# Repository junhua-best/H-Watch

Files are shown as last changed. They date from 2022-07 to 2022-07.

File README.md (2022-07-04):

# H-Watch
基于stm32L4系列的的低功耗智能手表
   智能手表是当前智能穿戴设备的主流产品之一。将手表内置智能化系统，连接于网络而实现多功能，可同步手机中的电话、短信、邮件、照片、音乐等。同时，智能手表还成为了运动的助手，可准确追踪走路的步数和消耗的能量；还可以通过内嵌的传感器，监测穿戴者的脉搏、心跳等身体状况的变化。近年来，智能手表热潮的掀起使得这一市场不断壮大，也有越来越多科技厂商投身其中。
	针对市面上的智能手表价格偏高，且普遍功耗表现差等特点，本文介绍了一种基于STM32l431系列的超低功耗微控制器的低成本智能手表“H-Watch”，从硬件到软件上的开发全过程。
	本文首先介绍了H-Watch的硬件相关的设置，搭载STM32L431CCU6的低功耗微控制器、低功耗蓝牙芯片、陀螺仪、温湿度传感器、磁力计、触摸按钮、振动马达、LCD屏幕等硬件外设，本文前期阐述了这些硬件在H-Watch中起到的作用。而在显示方面，H-Watch移植了业界常用的LVGL图形库，H-Watch拥有多个精美的界面，并具有流畅的动画效果，本文将在软件上仿真的效果以及实际手表的显示效果以图片的形式呈现。在操作系统方面，为了系统性能最大化、多个模块互相不耦合等特点，H-Watch使用FREERTOS实时操作系统，在H-Watch的研发过程中，软件系统设计被视作最为重要的一部分，本文着重阐述了各个功能模块的软件设计。
  本文将H-Watch的显示根据功能拆分设计为七个页面：主界面、关于、设置、备忘录、秒表、亮度设置、菜单。在软件系统层面拆分成六个主任务：蓝牙通信、时间更新、传感器数据更新、睡眠检测、按键更新、LVGL更新。H-Watch最终具有的功能包括：秒表、时间设置、亮度控制、时间日期显示、天气显示、温湿度值显示、电量值显示、步数记录、备忘录等。在续航方面，能够做到一次充电后，可以正常使用两个月的时间。

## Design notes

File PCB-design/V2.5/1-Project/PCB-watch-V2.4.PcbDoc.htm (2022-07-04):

Reporting Options

# File in Newer Format

Date | : | 2022/4/30
Time | : | 0:15:09
Filename | : | D:\作业文档\毕业设计_智能手表\裸跑版参考\原版资源图片\Hwatch-master\2-PCB-design\V2.5\1-Project\PCB-watch-V2.4.PcbDoc

Version | Warning
Release 15.1 | CAUTION - Support Multi-line PCB Text added.
Release 16.0 | CAUTION - Pad/Via hole size tolerance value added.
Release 17.0 | CAUTION - Component parameters added.
Release 17.0 | CAUTION - Support of backdrilling
Release 17.1 | CAUTION - Support of waived violations
Release 17.1 | CAUTION - Support of object specific keepouts
Release 20.0 | CAUTION - Support of propagation delay for primitives

This file was generated by a later version of the software

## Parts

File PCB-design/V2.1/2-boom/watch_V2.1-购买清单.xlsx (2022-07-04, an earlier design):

Comment | Description | Designator | Footprint | LibRef | Quantity
AN9520-245 | 2.4G全向天线 蓝牙天线 陶瓷贴片 WIFI内置 | AN1 | AN-5120 | AN9520-245 | 1
CC2541 | 低功耗蓝牙芯片 | B1 | QFN40-CC254X | CC2541 | 1
100nF | 0402封装电容, 贴片电容 | BC1, BC2, BC4, BC5, BC15, C5, C6, C9, C10, C11, C15, C16, C18, C19 | CC1005-0402 | Cap Chip 0402, Chip capacitor | 14
220PF | 0402封装电容 | BC3 | CC1005-0402 | Cap Chip 0402 | 1
18PF | 0402封装电容 | BC6, BC10 | CC1005-0402 | Cap Chip 0402 | 2
1PF | 0402封装电容, 贴片电容 | BC7, BC8, BC9, C7, C8 | CC1005-0402 | Cap Chip 0402, Chip capacitor | 5
15PF | 0402封装电容, 贴片电容 | BC11, BC14, C1, C2 | CC1005-0402 | Cap Chip 0402, Chip capacitor | 4
27PF | 0402封装电容 | BC12, BC13 | CC1005-0402 | Cap Chip 0402 | 2
1nH | 0402封装的电感 | BL1, BL2 | Inductor-0402 | Inductor-0402 | 2
2nH | 0402封装的电感 | BL3, BL4, BL5 | Inductor-0402 | Inductor-0402 | 3
56KR | 贴片电阻 | BR1 | CR1005-0402 | Chip resistor | 1
22pF | 贴片电容 | C3, C4 | CC1005-0402 | Chip capacitor | 2
4.7uF | 贴片电容 | C12 | CC1005-0402 | Chip capacitor | 1
2.2uF | 贴片电容 | C13 | CC1005-0402 | Chip capacitor | 1
0.22uF | 贴片电容 | C14 | CC1005-0402 | Chip capacitor | 1
10uF | 贴片电容 | C17, C20, C21 | CC1005-0402 | Chip capacitor | 3
1uF | 贴片电容 | C22, C24 | CC1005-0402 | Chip capacitor | 2
10nF | 贴片电容 | C23, C25 | CC1005-0402 | Chip capacitor | 2
TFT LED | 1.3寸显示屏幕 | L1 | LCD-1.3-(2) | LCD-IPSscreen-1.3 | 1
3.3uH | 贴片电感 | L2 | Inductor-0805 | Chip inductor | 1
power |  | P2, P3 | POWER-3.7V | power | 2
10KR | 贴片电阻 | R1, R2 | CR1005-0402 | Chip resistor | 2
1K | 贴片电阻 | R3, R21, R22, R24 | CR1005-0402 | Chip resistor | 4
10K | 贴片电阻 | R4, R8, R9, R10, R11, R12, R17, R18, R19, R20, R25, R26, R27 | CR1005-0402 | Chip resistor | 13
47K | 贴片电阻 | R5, R6, R7 | CR1005-0402 | Chip resistor | 3
1M | 贴片电阻 | R13 | CR1005-0402 | Chip resistor | 1
178K | 贴片电阻 | R14 | CR1005-0402 | Chip resistor | 1
1.5K | 贴片电阻 | R15, R16 | CR1005-0402 | Chip resistor | 2
2K | 贴片电阻 | R23 | CR1005-0402 | Chip resistor | 1
SH1.0-7P | 间距为1mm的端子 | SH1 | SH1.0-6P | SH1.0-7P | 1
STM32L431CCU6 | stm32低功耗单片机 主频80MHz | U1 | STM32-UFQFPN48_N | STM32L431CCU6 | 1
BS812A-1 | 触摸按键 两路 SOP23-6封装极简电路 | U2 | SOT23-6 | BS812A-1 | 1
W25Q256JVEIQ | FLASH | U3 | WSON-8_L8.0-W6.10-P1.27-TL-EP | W25Q256JVEIQ | 1
MMBT3904TT1G | NPN 电流 - 集电极（Ic）（最大值）：200mA 电压 - 集射极击穿（最大值）：40V SOT-23-3 | U4, U12 | SOT-416 | MMBT3904TT1G | 2
HMC5883L | 三轴罗盘 | U5 | LPCC-16_L3.0-W3.0-P0.50-BL | HMC5883L | 1
MPU6050 | 陀螺仪 | U6 | QFN24 - duplicate | MPU6050 | 1
SI7020 | 温湿度传感器芯片 | U7 | DFN-6 | SI7020 | 1
TPS22965 | DFN-8 功率开关芯片 TPS22965DSGR | U8 | UDFN-8 | TPS22965 | 1
TPS63000 | 宽电压电源转换芯片输出3.3V输入1V至6V | U9 | SON10 | TPS63000 | 1
CH340E | usd转串口芯片 MSOP10封装 | U10 | MSOP-10 | CH340E | 1
BQ24040 | 1A 具有自动启动功能的单输入，单节锂离子和锂聚合物电池充电 器 | U11 | WSON-10_L2.0-W2.0-P0.40-BL-EP | BQ24041 | 1
Tpye-c 16P | 16P 封装的TYPE -c接口 4固定插脚 双向 | USB1 | TYPE-C 16P | Tpye-c 16P | 1
32.768Khz | 2012封装的时钟晶振 | X1, X4 | XTAL-2012 | XTAL 2012 | 2
32Mhz | 2016封装的晶振 | X2, X3 | XTAL-2016 | XTAL 2016 | 2

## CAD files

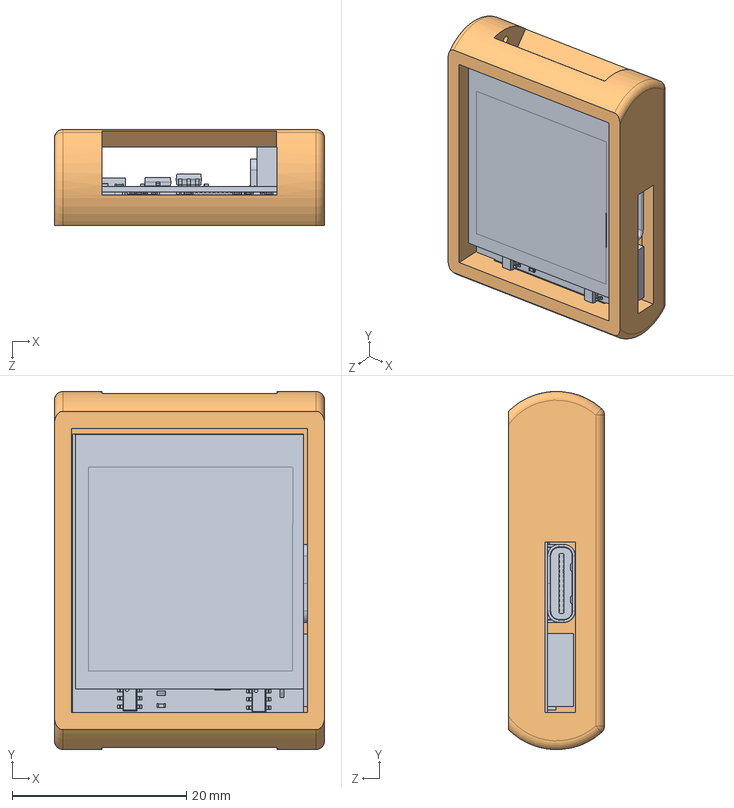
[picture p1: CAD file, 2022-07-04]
3D_design/装配体3.SLDASM
31.0 x 41.0 x 11.0 mm
PCB-watch-V2
外壳

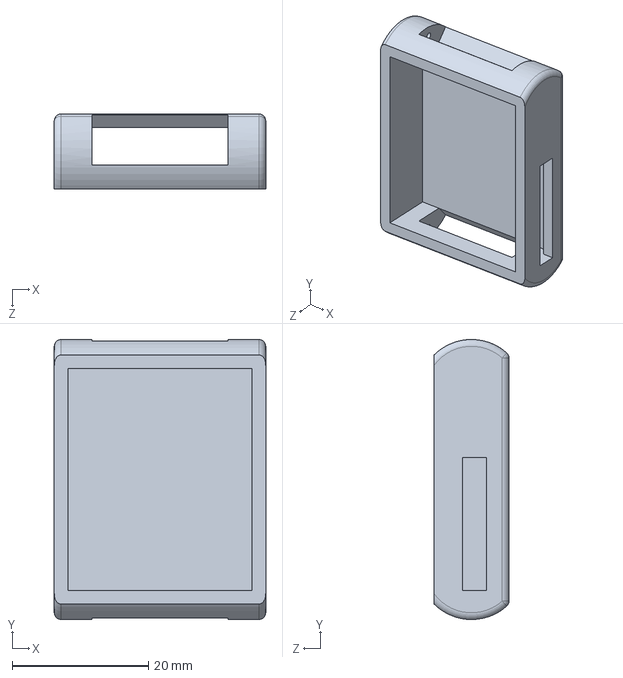
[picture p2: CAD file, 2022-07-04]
3D_design/外壳.SLDPRT
31.0 x 41.0 x 11.0 mm

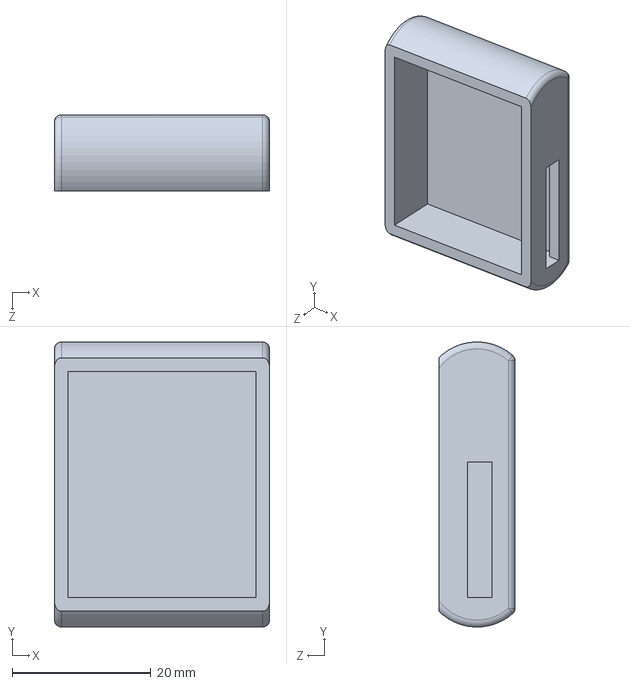
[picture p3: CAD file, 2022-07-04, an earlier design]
3D_design/外壳 - 副本.SLDPRT
31.0 x 41.0 x 11.0 mm

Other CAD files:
3D_design/外壳.STL

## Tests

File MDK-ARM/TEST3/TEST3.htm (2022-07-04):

# Static Call Graph for image TEST3\TEST3.axf

#<CALLGRAPH># ARM Linker, 5060960: Last Updated: Mon Jul 04 18:24:46 2022

### Maximum Stack Usage = 948 bytes + Unknown(Cycles, Untraceable Function Pointers)

### Call chain for Maximum Stack Depth:

lv_img_design ⇒ lv_draw_img ⇒ lv_img_draw_core ⇒ lv_draw_label ⇒ lv_draw_rect ⇒ lv_draw_shadow ⇒ lv_draw_shadow_full ⇒ lv_draw_shadow_full_straight ⇒ lv_draw_fill ⇒ sw_color_fill ⇒ lv_color_mix

### Mutually Recursive functions

- ADC1_IRQHandler ⇒ ADC1_IRQHandler
- lv_obj_get_screen ⇒ lv_obj_get_screen
- refresh_children_position ⇒ refresh_children_position
- BusFault_Handler ⇒ BusFault_Handler
- HardFault_Handler ⇒ HardFault_Handler
- MemManage_Handler ⇒ MemManage_Handler
- UsageFault_Handler ⇒ UsageFault_Handler
- lv_refr_obj ⇒ lv_refr_obj
- lv_refr_get_top_obj ⇒ lv_refr_get_top_obj
- lv_event_send_func ⇒ lv_event_send
- indev_search_obj ⇒ indev_search_obj
- report_style_mod_core ⇒ report_style_mod_core
- refresh_children_style ⇒ refresh_children_style

### Function Pointers

- ADC1_IRQHandler from startup_stm32l431xx.o(.text) referenced from startup_stm32l431xx.o(RESET)
- Ble_task from freertos.o(i.Ble_task) referenced from freertos.o(i.MX_FREERTOS_Init)
- BusFault_Handler from stm32l4xx_it.o(i.BusFault_Handler) referenced from startup_stm32l431xx.o(RESET)
- Button_task from freertos.o(i.Button_task) referenced from freertos.o(i.MX_FREERTOS_Init)
- CAN1_RX0_IRQHandler from startup_stm32l431xx.o(.text) referenced from startup_stm32l431xx.o(RESET)
- CAN1_RX1_IRQHandler from startup_stm32l431xx.o(.text) referenced from startup_stm32l431xx.o(RESET)
- CAN1_SCE_IRQHandler from startup_stm32l431xx.o(.text) referenced from startup_stm32l431xx.o(RESET)
- CAN1_TX_IRQHandler from startup_stm32l431xx.o(.text) referenced from startup_stm32l431xx.o(RESET)
- COMP_IRQHandler from startup_stm32l431xx.o(.text) referenced from startup_stm32l431xx.o(RESET)
- CRS_IRQHandler from startup_stm32l431xx.o(.text) referenced from startup_stm32l431xx.o(RESET)
- DMA1_Channel1_IRQHandler from startup_stm32l431xx.o(.text) referenced from startup_stm32l431xx.o(RESET)
- DMA1_Channel2_IRQHandler from startup_stm32l431xx.o(.text) referenced from startup_stm32l431xx.o(RESET)
- DMA1_Channel3_IRQHandler from stm32l4xx_it.o(i.DMA1_Channel3_IRQHandler) referenced from startup_stm32l431xx.o(RESET)
- DMA1_Channel4_IRQHandler from stm32l4xx_it.o(i.DMA1_Channel4_IRQHandler) referenced from startup_stm32l431xx.o(RESET)
- DMA1_Channel5_IRQHandler from stm32l4xx_it.o(i.DMA1_Channel5_IRQHandler) referenced from startup_stm32l431xx.o(RESET)
- DMA1_Channel6_IRQHandler from stm32l4xx_it.o(i.DMA1_Channel6_IRQHandler) referenced from startup_stm32l431xx.o(RESET)
- DMA1_Channel7_IRQHandler from stm32l4xx_it.o(i.DMA1_Channel7_IRQHandler) referenced from startup_stm32l431xx.o(RESET)
- DMA2_Channel1_IRQHandler from startup_stm32l431xx.o(.text) referenced from startup_stm32l431xx.o(RESET)
- DMA2_Channel2_IRQHandler from startup_stm32l431xx.o(.text) referenced from startup_stm32l431xx.o(RESET)
- DMA2_Channel3_IRQHandler from startup_stm32l431xx.o(.text) referenced from startup_stm32l431xx.o(RESET)
- DMA2_Channel4_IRQHandler from startup_stm32l431xx.o(.text) referenced from startup_stm32l431xx.o(RESET)
- DMA2_Channel5_IRQHandler from startup_stm32l431xx.o(.text) referenced from startup_stm32l431xx.o(RESET)
- DMA2_Channel6_IRQHandler from startup_stm32l431xx.o(.text) referenced from startup_stm32l431xx.o(RESET)
- DMA2_Channel7_IRQHandler from startup_stm32l431xx.o(.text) referenced from startup_stm32l431xx.o(RESET)
- Data_task from freertos.o(i.Data_task) referenced from freertos.o(i.MX_FREERTOS_Init)
- DebugMon_Handler from stm32l4xx_it.o(i.DebugMon_Handler) referenced from startup_stm32l431xx.o(RESET)
- EXTI0_IRQHandler from stm32l4xx_it.o(i.EXTI0_IRQHandler) referenced from startup_stm32l431xx.o(RESET)
- EXTI15_10_IRQHandler from stm32l4xx_it.o(i.EXTI15_10_IRQHandler) referenced from startup_stm32l431xx.o(RESET)
- EXTI1_IRQHandler from startup_stm32l431xx.o(.text) referenced from startup_stm32l431xx.o(RESET)
- EXTI2_IRQHandler from startup_stm32l431xx.o(.text) referenced from startup_stm32l431xx.o(RESET)
- EXTI3_IRQHandler from startup_stm32l431xx.o(.text) referenced from startup_stm32l431xx.o(RESET)
- EXTI4_IRQHandler from startup_stm32l431xx.o(.text) referenced from startup_stm32l431xx.o(RESET)
- EXTI9_5_IRQHandler from startup_stm32l431xx.o(.text) referenced from startup_stm32l431xx.o(RESET)
- FLASH_IRQHandler from startup_stm32l431xx.o(.text) referenced from startup_stm32l431xx.o(RESET)
- FPU_IRQHandler from startup_stm32l431xx.o(.text) referenced from startup_stm32l431xx.o(RESET)
- HardFault_Handler from stm32l4xx_it.o(i.HardFault_Handler) referenced from startup_stm32l431xx.o(RESET)
- I2C1_ER_IRQHandler from startup_stm32l431xx.o(.text) referenced from startup_stm32l431xx.o(RESET)
- I2C1_EV_IRQHandler from startup_stm32l431xx.o(.text) referenced from startup_stm32l431xx.o(RESET)
- I2C2_ER_IRQHandler from startup_stm32l431xx.o(.text) referenced from startup_stm32l431xx.o(RESET)
- I2C2_EV_IRQHandler from startup_stm32l431xx.o(.text) referenced from startup_stm32l431xx.o(RESET)
- I2C3_ER_IRQHandler from startup_stm32l431xx.o(.text) referenced from startup_stm32l431xx.o(RESET)
- I2C3_EV_IRQHandler from startup_stm32l431xx.o(.text) referenced from startup_stm32l431xx.o(RESET)
- LPTIM1_IRQHandler from startup_stm32l431xx.o(.text) referenced from startup_stm32l431xx.o(RESET)
- LPTIM2_IRQHandler from startup_stm32l431xx.o(.text) referenced from startup_stm32l431xx.o(RESET)
- LPUART1_IRQHandler from startup_stm32l431xx.o(.text) referenced from startup_stm32l431xx.o(RESET)
- MemManage_Handler from stm32l4xx_it.o(i.MemManage_Handler) referenced from startup_stm32l431xx.o(RESET)
- NMI_Handler from stm32l4xx_it.o(i.NMI_Handler) referenced from startup_stm32l431xx.o(RESET)
- PVD_PVM_IRQHandler from startup_stm32l431xx.o(.text) referenced from startup_stm32l431xx.o(RESET)
- PendSV_Handler from port.o(.emb_text) referenced from startup_stm32l431xx.o(RESET)
- QUADSPI_IRQHandler from startup_stm32l431xx.o(.text) referenced from startup_stm32l431xx.o(RESET)
- RCC_IRQHandler from startup_stm32l431xx.o(.text) referenced from startup_stm32l431xx.o(RESET)
- RNG_IRQHandler from startup_stm32l431xx.o(.text) referenced from startup_stm32l431xx.o(RESET)
- RTC_Alarm_IRQHandler from stm32l4xx_it.o(i.RTC_Alarm_IRQHandler) referenced from startup_stm32l431xx.o(RESET)
- RTC_WKUP_IRQHandler from startup_stm32l431xx.o(.text) referenced from startup_stm32l431xx.o(RESET)
- Reset_Handler from startup_stm32l431xx.o(.text) referenced from startup_stm32l431xx.o(RESET)
- SAI1_IRQHandler from startup_stm32l431xx.o(.text) referenced from startup_stm32l431xx.o(RESET)
- SDMMC1_IRQHandler from startup_stm32l431xx.o(.text) referenced from startup_stm32l431xx.o(RESET)
- SPI1_IRQHandler from startup_stm32l431xx.o(.text) referenced from startup_stm32l431xx.o(RESET)
- SPI2_IRQHandler from startup_stm32l431xx.o(.text) referenced from startup_stm32l431xx.o(RESET)
- SPI3_IRQHandler from startup_stm32l431xx.o(.text) referenced from startup_stm32l431xx.o(RESET)
- SVC_Handler from port.o(.emb_text) referenced from startup_stm32l431xx.o(RESET)
- SWPMI1_IRQHandler from startup_stm32l431xx.o(.text) referenced from startup_stm32l431xx.o(RESET)
- SW_LabelUpdate from stopwatch_page.o(i.SW_LabelUpdate) referenced from stopwatch_page.o(i.LmeterSec_Create)
- Sensor_task from freertos.o(i.Sensor_task) referenced from freertos.o(i.MX_FREERTOS_Init)
- Sleep_task from freertos.o(i.Sleep_task) referenced from freertos.o(i.MX_FREERTOS_Init)
- SysTick_Handler from port.o(i.SysTick_Handler) referenced from startup_stm32l431xx.o(RESET)
- SystemInit from system_stm32l4xx.o(i.SystemInit) referenced from startup_stm32l431xx.o(.text)
- TAMP_STAMP_IRQHandler from startup_stm32l431xx.o(.text) referenced from startup_stm32l431xx.o(RESET)
- TIM1_BRK_TIM15_IRQHandler from startup_stm32l431xx.o(.text) referenced from startup_stm32l431xx.o(RESET)
- TIM1_CC_IRQHandler from startup_stm32l431xx.o(.text) referenced from startup_stm32l431xx.o(RESET)
- TIM1_TRG_COM_IRQHandler from startup_stm32l431xx.o(.text) referenced from startup_stm32l431xx.o(RESET)
- TIM1_UP_TIM16_IRQHandler from startup_stm32l431xx.o(.text) referenced from startup_stm32l431xx.o(RESET)
- TIM2_IRQHandler from startup_stm32l431xx.o(.text) referenced from startup_stm32l431xx.o(RESET)
- TIM6_DAC_IRQHandler from stm32l4xx_it.o(i.TIM6_DAC_IRQHandler) referenced from startup_stm32l431xx.o(RESET)
- TIM7_IRQHandler from stm32l4xx_it.o(i.TIM7_IRQHandler) referenced from startup_stm32l431xx.o(RESET)
- TSC_IRQHandler from startup_stm32l431xx.o(.text) referenced from startup_stm32l431xx.o(RESET)
- UART_DMAAbortOnError from stm32l4xx_hal_uart.o(i.UART_DMAAbortOnError) referenced from stm32l4xx_hal_uart.o(i.HAL_UART_IRQHandler)
- UART_DMAError from stm32l4xx_hal_uart.o(i.UART_DMAError) referenced from stm32l4xx_hal_uart.o(i.HAL_UART_Receive_DMA)
- UART_DMAReceiveCplt from stm32l4xx_hal_uart.o(i.UART_DMAReceiveCplt) referenced from stm32l4xx_hal_uart.o(i.HAL_UART_Receive_DMA)
- UART_DMARxHalfCplt from stm32l4xx_hal_uart.o(i.UART_DMARxHalfCplt) referenced from stm32l4xx_hal_uart.o(i.HAL_UART_Receive_DMA)
- USART1_IRQHandler from stm32l4xx_it.o(i.USART1_IRQHandler) referenced from startup_stm32l431xx.o(RESET)
- USART2_IRQHandler from stm32l4xx_it.o(i.USART2_IRQHandler) referenced from startup_stm32l431xx.o(RESET)
- USART3_IRQHandler from startup_stm32l431xx.o(.text) referenced from startup_stm32l431xx.o(RESET)
- UsageFault_Handler from stm32l4xx_it.o(i.UsageFault_Handler) referenced from startup_stm32l431xx.o(RESET)
- WWDG_IRQHandler from startup_stm32l431xx.o(.text) referenced from startup_stm32l431xx.o(RESET)
- __main from entry.o(.ARM.Collect$$$$00000000) referenced from startup_stm32l431xx.o(.text)
- _sputc from printfa.o(i._sputc) referenced from printfa.o(i.__0sprintf)
- anim_task from lv_anim.o(i.anim_task) referenced from lv_anim.o(i.lv_anim_core_init)
- astronauts_task_cb from watch_page.o(i.astronauts_task_cb) referenced from watch_page.o(i.app_digital_clock_create)
- button_read from lv_port_indev.o(i.button_read) referenced from lv_port_indev.o(i.lv_port_indev_init)
- data_update_task_cb from watch_page.o(i.data_update_task_cb) referenced from watch_page.o(i.app_digital_clock_create)
- deg_test_inv from lv_draw_arc.o(i.deg_test_inv) referenced from lv_draw_arc.o(i.lv_draw_arc)
- deg_test_norm from lv_draw_arc.o(i.deg_test_norm) referenced from lv_draw_arc.o(i.lv_draw_arc)
- disp_flush from lv_port_disp.o(i.disp_flush) referenced from lv_port_disp.o(i.lv_port_disp_init)
- edge_flash_anim from lv_page.o(i.edge_flash_anim) referenced from lv_page.o(i.lv_page_start_edge_flash)
- edge_flash_anim_end from lv_page.o(i.edge_flash_anim_end) referenced from lv_page.o(i.lv_page_start_edge_flash)
- fputc from main.o(i.fputc) referenced from printfa.o(i.__0printf)
- kern_pair_16_compare from lv_font_fmt_txt.o(i.kern_pair_16_compare) referenced from lv_font_fmt_txt.o(i.get_kern_value)
- kern_pair_8_compare from lv_font_fmt_txt.o(i.kern_pair_8_compare) referenced from lv_font_fmt_txt.o(i.get_kern_value)
- lv_anim_path_bounce from lv_anim.o(i.lv_anim_path_bounce) referenced from about_page.o(i.app_about_anim_Hexit)
- lv_anim_path_bounce from lv_anim.o(i.lv_anim_path_bounce) referenced from watch_page.o(i.app_digital_clock_meun_re)
- lv_anim_path_bounce from lv_anim.o(i.lv_anim_path_bounce) referenced from light_setting_page.o(i.app_lighting_anim_Hexit_img)
- lv_anim_path_bounce from lv_anim.o(i.lv_anim_path_bounce) referenced from memo_page.o(i.app_memo_anim_Hexit)
- lv_anim_path_bounce from lv_anim.o(i.lv_anim_path_bounce) referenced from menu_page.o(i.app_menu_anim_Hexit_about_img)
- lv_anim_path_bounce from lv_anim.o(i.lv_anim_path_bounce) referenced from menu_page.o(i.app_menu_anim_Hexit_light_img)
- lv_anim_path_bounce from lv_anim.o(i.lv_anim_path_bounce) referenced from menu_page.o(i.app_menu_anim_Hexit_memo_img)
- lv_anim_path_bounce from lv_anim.o(i.lv_anim_path_bounce) referenced from menu_page.o(i.app_menu_anim_Hexit_setting_img)
- lv_anim_path_bounce from lv_anim.o(i.lv_anim_path_bounce) referenced from menu_page.o(i.app_menu_anim_Hexit_stopwatch_img)
- lv_anim_path_bounce from lv_anim.o(i.lv_anim_path_bounce) referenced from menu_page.o(i.app_menu_anim_Vexit_about_img)
- lv_anim_path_bounce from lv_anim.o(i.lv_anim_path_bounce) referenced from menu_page.o(i.app_menu_anim_Vexit_light_img)
- lv_anim_path_bounce from lv_anim.o(i.lv_anim_path_bounce) referenced from menu_page.o(i.app_menu_anim_Vexit_memo_img)
- lv_anim_path_bounce from lv_anim.o(i.lv_anim_path_bounce) referenced from menu_page.o(i.app_menu_anim_Vexit_setting_img)
- lv_anim_path_bounce from lv_anim.o(i.lv_anim_path_bounce) referenced from menu_page.o(i.app_menu_anim_Vexit_stopwatch_img)
- lv_anim_path_bounce from lv_anim.o(i.lv_anim_path_bounce) referenced from time_setting_page.o(i.app_setting_anim_Vexit)
- lv_anim_path_bounce from lv_anim.o(i.lv_anim_path_bounce) referenced from stopwatch_page.o(i.app_stopwatch_anim_Hexit_img)
- lv_anim_path_bounce from lv_anim.o(i.lv_anim_path_bounce) referenced from menu_page.o(i.app_tip_anim_Vexit)
- lv_anim_path_linear from lv_anim.o(i.lv_anim_path_linear) referenced from lv_anim.o(i.lv_anim_init)
- lv_anim_path_linear from lv_anim.o(i.lv_anim_path_linear) referenced from lv_ddlist.o(i.lv_ddlist_refr_size)
- lv_anim_path_linear from lv_anim.o(i.lv_anim_path_linear) referenced from lv_label.o(i.lv_label_refr_text)
- lv_anim_path_linear from lv_anim.o(i.lv_anim_path_linear) referenced from lv_page.o(i.lv_page_scroll_hor)
- lv_anim_path_linear from lv_anim.o(i.lv_anim_path_linear) referenced from lv_page.o(i.lv_page_scroll_ver)
- lv_anim_path_linear from lv_anim.o(i.lv_anim_path_linear) referenced from lv_page.o(i.lv_page_start_edge_flash)
- lv_anim_path_linear from lv_anim.o(i.lv_anim_path_linear) referenced from lv_roller.o(i.refr_position)
- lv_arc_design from lv_arc.o(i.lv_arc_design) referenced from lv_arc.o(i.lv_arc_create)
- lv_arc_signal from lv_arc.o(i.lv_arc_signal) referenced from lv_arc.o(i.lv_arc_create)
- lv_btn_design from lv_btn.o(i.lv_btn_design) referenced from lv_btn.o(i.lv_btn_create)
- lv_btn_signal from lv_btn.o(i.lv_btn_signal) referenced from lv_btn.o(i.lv_btn_create)
- lv_cont_signal from lv_cont.o(i.lv_cont_signal) referenced from lv_cont.o(i.lv_cont_create)
- lv_ddlist_adjust_height from lv_ddlist.o(i.lv_ddlist_adjust_height) referenced from lv_ddlist.o(i.lv_ddlist_refr_size)
- lv_ddlist_anim_ready_cb from lv_ddlist.o(i.lv_ddlist_anim_ready_cb) referenced from lv_ddlist.o(i.lv_ddlist_refr_size)
- lv_ddlist_design from lv_ddlist.o(i.lv_ddlist_design) referenced from lv_ddlist.o(i.lv_ddlist_create)
- lv_ddlist_scrl_signal from lv_ddlist.o(i.lv_ddlist_scrl_signal) referenced from lv_ddlist.o(i.lv_ddlist_create)
- lv_ddlist_signal from lv_ddlist.o(i.lv_ddlist_signal) referenced from lv_ddlist.o(i.lv_ddlist_create)
- lv_disp_refr_task from lv_refr.o(i.lv_disp_refr_task) referenced from lv_hal_disp.o(i.lv_disp_drv_register)
- lv_font_get_bitmap_fmt_txt from lv_font_fmt_txt.o(i.lv_font_get_bitmap_fmt_txt) referenced 10 times from lv_font_roboto_16.o(.data)
- lv_font_get_glyph_dsc_fmt_txt from lv_font_fmt_txt.o(i.lv_font_get_glyph_dsc_fmt_txt) referenced 10 times from lv_font_roboto_16.o(.data)
- lv_img_decoder_built_in_close from lv_img_decoder.o(i.lv_img_decoder_built_in_close) referenced from lv_img_decoder.o(i.lv_img_decoder_init)
- lv_img_decoder_built_in_info from lv_img_decoder.o(i.lv_img_decoder_built_in_info) referenced from lv_img_decoder.o(i.lv_img_decoder_init)
- lv_img_decoder_built_in_open from lv_img_decoder.o(i.lv_img_decoder_built_in_open) referenced from lv_img_decoder.o(i.lv_img_decoder_init)
- lv_img_decoder_built_in_read_line from lv_img_decoder.o(i.lv_img_decoder_built_in_read_line) referenced from lv_img_decoder.o(i.lv_img_decoder_init)
- lv_img_design from lv_img.o(i.lv_img_design) referenced from lv_img.o(i.lv_img_create)
- lv_img_signal from lv_img.o(i.lv_img_signal) referenced from lv_img.o(i.lv_img_create)
- lv_indev_read_task from lv_indev.o(i.lv_indev_read_task) referenced from lv_hal_indev.o(i.lv_indev_drv_register)
- lv_label_design from lv_label.o(i.lv_label_design) referenced from lv_label.o(i.lv_label_create)
- lv_label_set_offset_x from lv_label.o(i.lv_label_set_offset_x) referenced from lv_label.o(i.lv_label_refr_text)
- lv_label_set_offset_x from lv_label.o(i.lv_label_set_offset_x) referenced from lv_label.o(i.lv_label_set_long_mode)
- lv_label_set_offset_y from lv_label.o(i.lv_label_set_offset_y) referenced from lv_label.o(i.lv_label_refr_text)
- lv_label_set_offset_y from lv_label.o(i.lv_label_set_offset_y) referenced from lv_label.o(i.lv_label_set_long_mode)
- lv_label_signal from lv_label.o(i.lv_label_signal) referenced from lv_label.o(i.lv_label_create)
- lv_line_design from lv_line.o(i.lv_line_design) referenced from lv_line.o(i.lv_line_create)
- lv_line_signal from lv_line.o(i.lv_line_signal) referenced from lv_line.o(i.lv_line_create)
- lv_ll_get_head from lv_ll.o(i.lv_ll_get_head) referenced from lv_group.o(i.lv_group_focus_next)
- lv_ll_get_next from lv_ll.o(i.lv_ll_get_next) referenced from lv_group.o(i.lv_group_focus_next)
- lv_ll_get_prev from lv_ll.o(i.lv_ll_get_prev) referenced from lv_group.o(i.lv_group_focus_prev)
- lv_ll_get_tail from lv_ll.o(i.lv_ll_get_tail) referenced from lv_group.o(i.lv_group_focus_prev)
- lv_lmeter_design from lv_lmeter.o(i.lv_lmeter_design) referenced from lv_lmeter.o(i.lv_lmeter_create)
- lv_lmeter_signal from lv_lmeter.o(i.lv_lmeter_signal) referenced from lv_lmeter.o(i.lv_lmeter_create)
- lv_obj_design from lv_obj.o(i.lv_obj_design) referenced from lv_obj.o(i.lv_obj_create)
- lv_obj_set_x from lv_obj.o(i.lv_obj_set_x) referenced from about_page.o(i.app_about_anim_Hexit)
- lv_obj_set_x from lv_obj.o(i.lv_obj_set_x) referenced from light_setting_page.o(i.app_lighting_anim_Hexit_img)
- lv_obj_set_x from lv_obj.o(i.lv_obj_set_x) referenced from memo_page.o(i.app_memo_anim_Hexit)
- lv_obj_set_x from lv_obj.o(i.lv_obj_set_x) referenced from menu_page.o(i.app_menu_anim_Hexit_about_img)
- lv_obj_set_x from lv_obj.o(i.lv_obj_set_x) referenced from menu_page.o(i.app_menu_anim_Hexit_light_img)
- lv_obj_set_x from lv_obj.o(i.lv_obj_set_x) referenced from menu_page.o(i.app_menu_anim_Hexit_memo_img)
- lv_obj_set_x from lv_obj.o(i.lv_obj_set_x) referenced from menu_page.o(i.app_menu_anim_Hexit_setting_img)
- lv_obj_set_x from lv_obj.o(i.lv_obj_set_x) referenced from menu_page.o(i.app_menu_anim_Hexit_stopwatch_img)
- lv_obj_set_x from lv_obj.o(i.lv_obj_set_x) referenced from stopwatch_page.o(i.app_stopwatch_anim_Hexit_img)
- lv_obj_set_x from lv_obj.o(i.lv_obj_set_x) referenced from lv_label.o(i.lv_label_set_long_mode)
- lv_obj_set_x from lv_obj.o(i.lv_obj_set_x) referenced from lv_page.o(i.lv_page_scroll_hor)
- lv_obj_set_y from lv_obj.o(i.lv_obj_set_y) referenced from watch_page.o(i.app_digital_clock_meun_re)
- lv_obj_set_y from lv_obj.o(i.lv_obj_set_y) referenced from menu_page.o(i.app_menu_anim_Vexit_about_img)
- lv_obj_set_y from lv_obj.o(i.lv_obj_set_y) referenced from menu_page.o(i.app_menu_anim_Vexit_light_img)
- lv_obj_set_y from lv_obj.o(i.lv_obj_set_y) referenced from menu_page.o(i.app_menu_anim_Vexit_memo_img)
- lv_obj_set_y from lv_obj.o(i.lv_obj_set_y) referenced from menu_page.o(i.app_menu_anim_Vexit_setting_img)
- lv_obj_set_y from lv_obj.o(i.lv_obj_set_y) referenced from menu_page.o(i.app_menu_anim_Vexit_stopwatch_img)
- lv_obj_set_y from lv_obj.o(i.lv_obj_set_y) referenced from time_setting_page.o(i.app_setting_anim_Vexit)
- lv_obj_set_y from lv_obj.o(i.lv_obj_set_y) referenced from menu_page.o(i.app_tip_anim_Vexit)
- lv_obj_set_y from lv_obj.o(i.lv_obj_set_y) referenced from lv_label.o(i.lv_label_set_long_mode)
- lv_obj_set_y from lv_obj.o(i.lv_obj_set_y) referenced from lv_page.o(i.lv_page_scroll_ver)
- lv_obj_set_y from lv_obj.o(i.lv_obj_set_y) referenced from lv_roller.o(i.lv_roller_scrl_signal)
- lv_obj_set_y from lv_obj.o(i.lv_obj_set_y) referenced from lv_roller.o(i.lv_roller_signal)
- lv_obj_set_y from lv_obj.o(i.lv_obj_set_y) referenced from lv_roller.o(i.refr_height)
- lv_obj_set_y from lv_obj.o(i.lv_obj_set_y) referenced from lv_roller.o(i.refr_position)
- lv_obj_signal from lv_obj.o(i.lv_obj_signal) referenced from lv_obj.o(i.lv_obj_create)
- lv_page_design from lv_page.o(i.lv_page_design) referenced from lv_page.o(i.lv_page_create)
- lv_page_scrollable_signal from lv_page.o(i.lv_page_scrollable_signal) referenced from lv_page.o(i.lv_page_create)
- lv_page_signal from lv_page.o(i.lv_page_signal) referenced from lv_page.o(i.lv_page_create)
- lv_roller_design from lv_roller.o(i.lv_roller_design) referenced from lv_roller.o(i.lv_roller_create)
- lv_roller_scrl_signal from lv_roller.o(i.lv_roller_scrl_signal) referenced from lv_roller.o(i.lv_roller_create)
- lv_roller_signal from lv_roller.o(i.lv_roller_signal) referenced from lv_roller.o(i.lv_roller_create)
- lv_scrl_design from lv_page.o(i.lv_scrl_design) referenced from lv_page.o(i.lv_page_create)
- lv_task_handler_task from freertos.o(i.lv_task_handler_task) referenced from freertos.o(i.MX_FREERTOS_Init)
- lv_txt_utf8_get_byte_id from lv_txt.o(i.lv_txt_utf8_get_byte_id) referenced 2 times from lv_txt.o(.data)
- lv_txt_utf8_get_char_id from lv_txt.o(i.lv_txt_utf8_get_char_id) referenced 2 times from lv_txt.o(.data)
- lv_txt_utf8_get_length from lv_txt.o(i.lv_txt_utf8_get_length) referenced 2 times from lv_txt.o(.data)
- lv_txt_utf8_next from lv_txt.o(i.lv_txt_utf8_next) referenced 2 times from lv_txt.o(.data)
- lv_txt_utf8_prev from lv_txt.o(i.lv_txt_utf8_prev) referenced 2 times from lv_txt.o(.data)
- lv_txt_utf8_size from lv_txt.o(i.lv_txt_utf8_size) referenced 2 times from lv_txt.o(.data)
- main from main.o(i.main) referenced from entry9a.o(.ARM.Collect$$$$0000000B)
- mainWindow from gui_display.o(i.mainWindow) referenced from gui_display.o(.constdata)
- menu1 from gui_display.o(i.menu1) referenced from gui_display.o(.constdata)
- menu2 from gui_display.o(i.menu2) referenced from gui_display.o(.constdata)
- menu2_1 from gui_display.o(i.menu2_1) referenced from gui_display.o(.constdata)
- menu2_2 from gui_display.o(i.menu2_2) referenced from gui_display.o(.constdata)
- menu2_3 from gui_display.o(i.menu2_3) referenced from gui_display.o(.constdata)
- menu2_4 from gui_display.o(i.menu2_4) referenced from gui_display.o(.constdata)
- menu2_5 from gui_display.o(i.menu2_5) referenced from gui_display.o(.constdata)
- menu2_6 from gui_display.o(i.menu2_6) referenced from gui_display.o(.constdata)
- menu2_7 from gui_display.o(i.menu2_7) referenced from gui_display.o(.constdata)
- menu3 from gui_display.o(i.menu3) referenced from gui_display.o(.constdata)
- menu4 from gui_display.o(i.menu4) referenced from gui_display.o(.constdata)
- menu5 from gui_display.o(i.menu5) referenced from gui_display.o(.constdata)
- menu6 from gui_display.o(i.menu6) referenced from gui_display.o(.constdata)
- menu7 from gui_display.o(i.menu7) referenced from gui_display.o(.constdata)
- prvIdleTask from tasks.o(i.prvIdleTask) referenced from tasks.o(i.vTaskStartScheduler)
- prvTaskExitError from port.o(i.prvTaskExitError) referenced from port.o(i.pxPortInitialiseStack)
- prvTimerTask from timers.o(i.prvTimerTask) referenced from timers.o(i.xTimerCreateTimerTask)
- scrl_def_event_cb from lv_page.o(i.scrl_def_event_cb) referenced from lv_page.o(i.lv_page_create)
- scroll_anim_ready_cb from lv_roller.o(i.scroll_anim_ready_cb) referenced from lv_roller.o(i.refr_position)
- style_mod from lv_theme_mono.o(i.style_mod) referenced from lv_theme_mono.o(i.lv_theme_mono_init)
- style_mod_def from lv_group.o(i.style_mod_def) referenced from lv_group.o(i.refresh_theme)
- style_mod_edit from lv_theme_mono.o(i.style_mod_edit) referenced from lv_theme_mono.o(i.lv_theme_mono_init)
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

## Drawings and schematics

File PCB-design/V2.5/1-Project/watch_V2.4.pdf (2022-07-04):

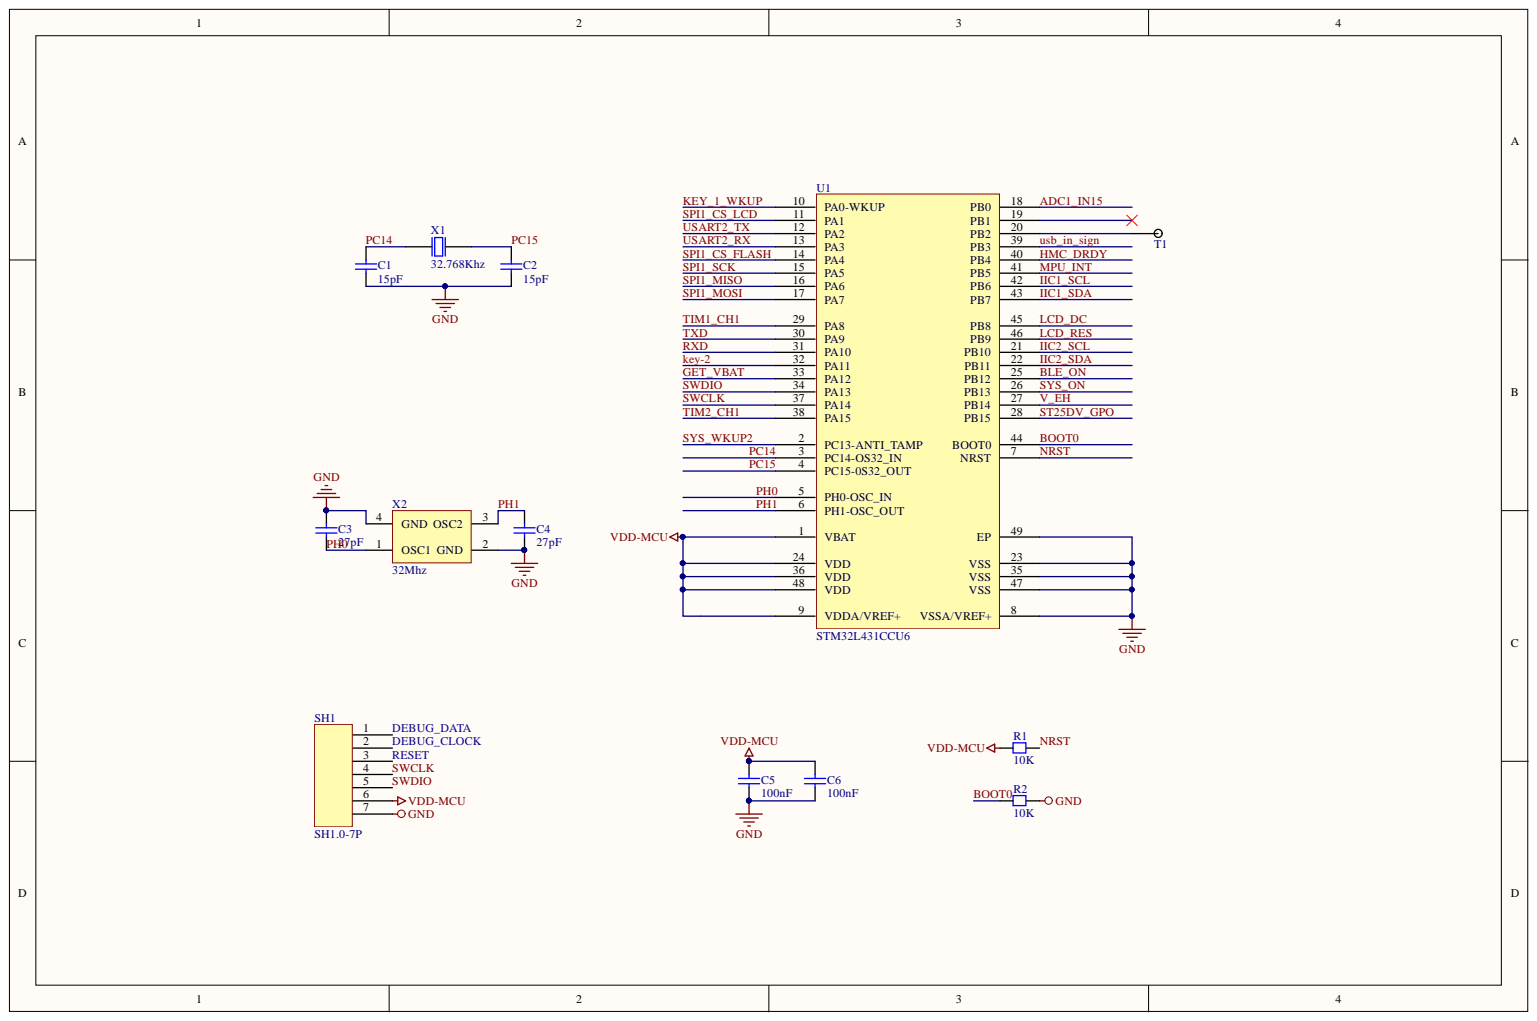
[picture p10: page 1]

VDD 24

VDD 48

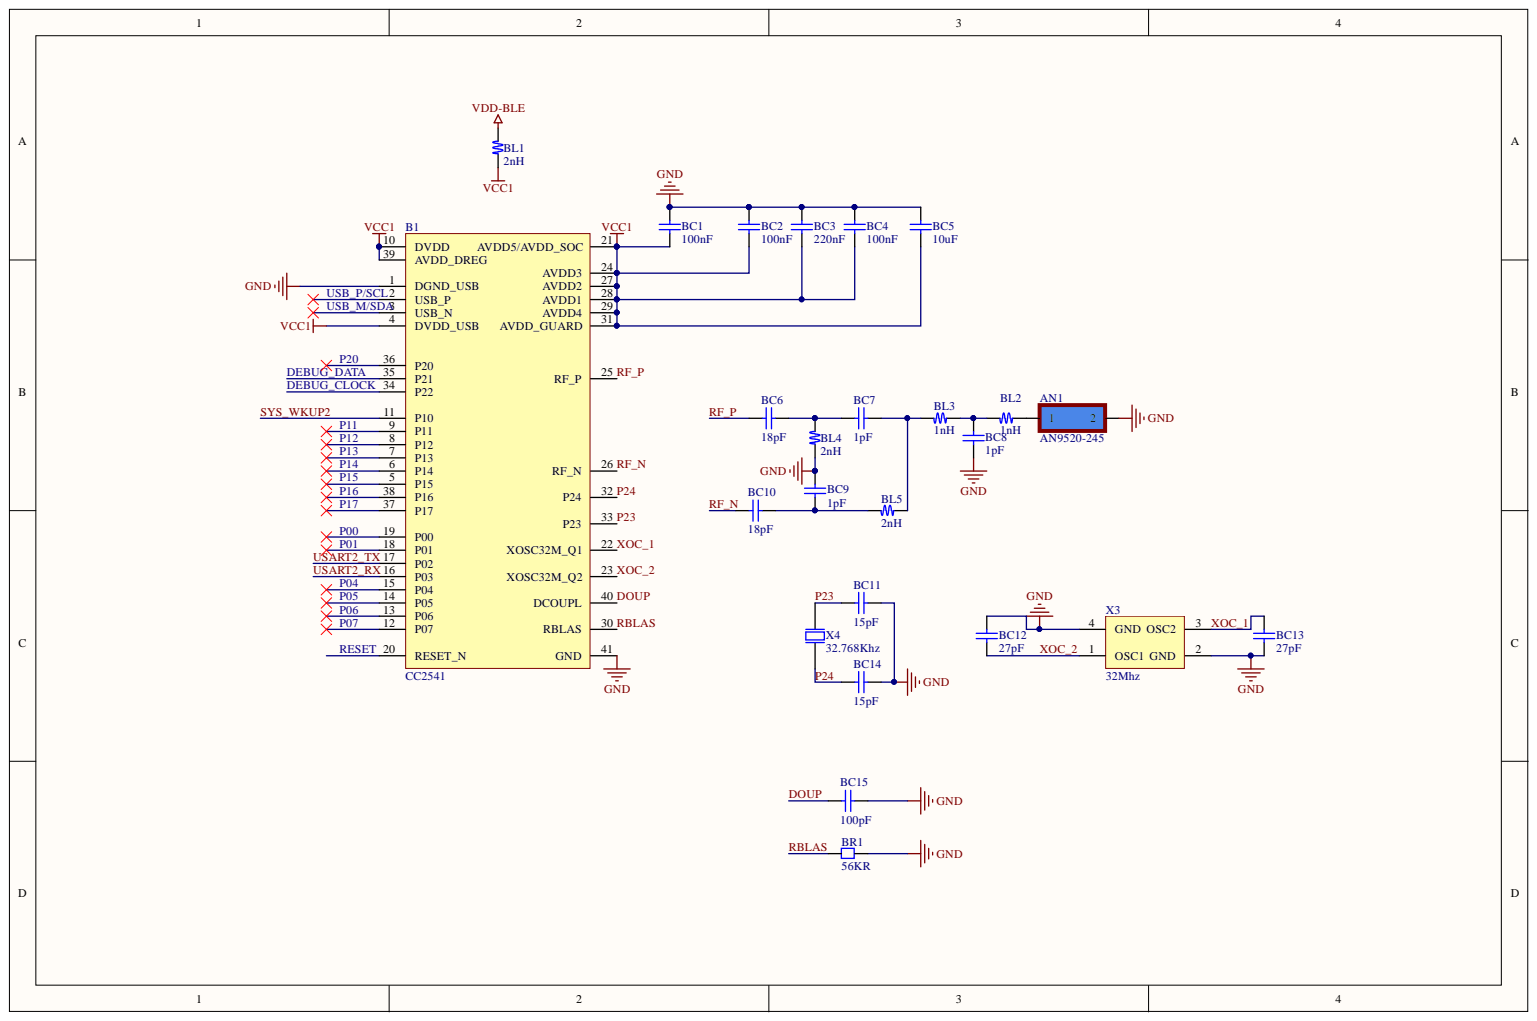
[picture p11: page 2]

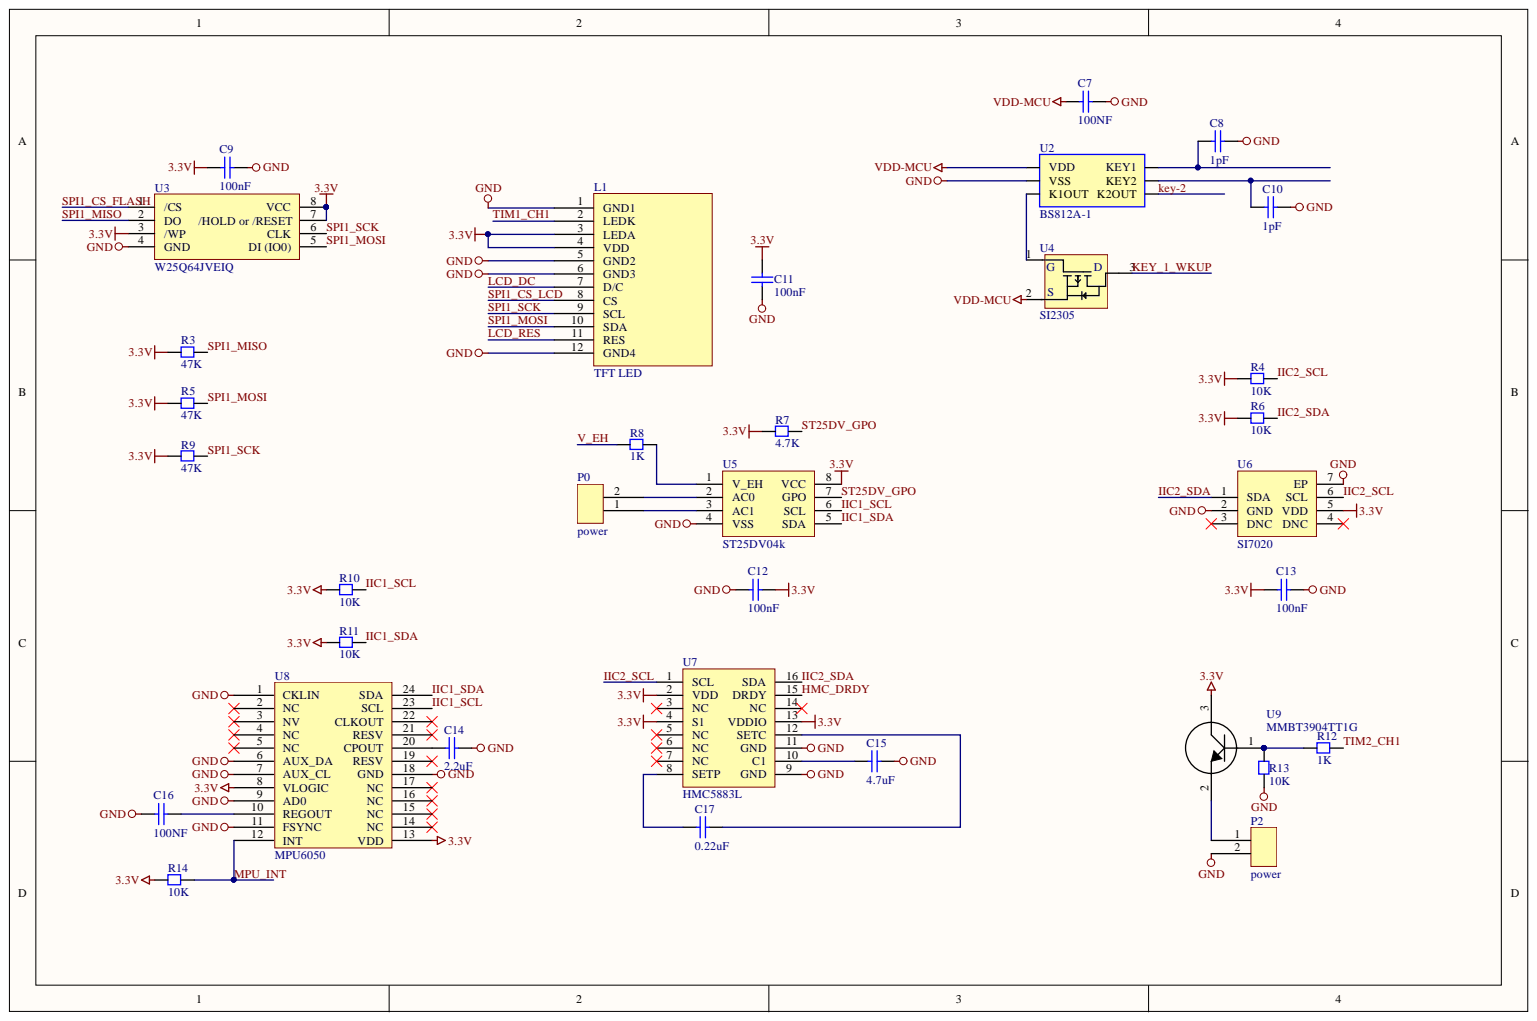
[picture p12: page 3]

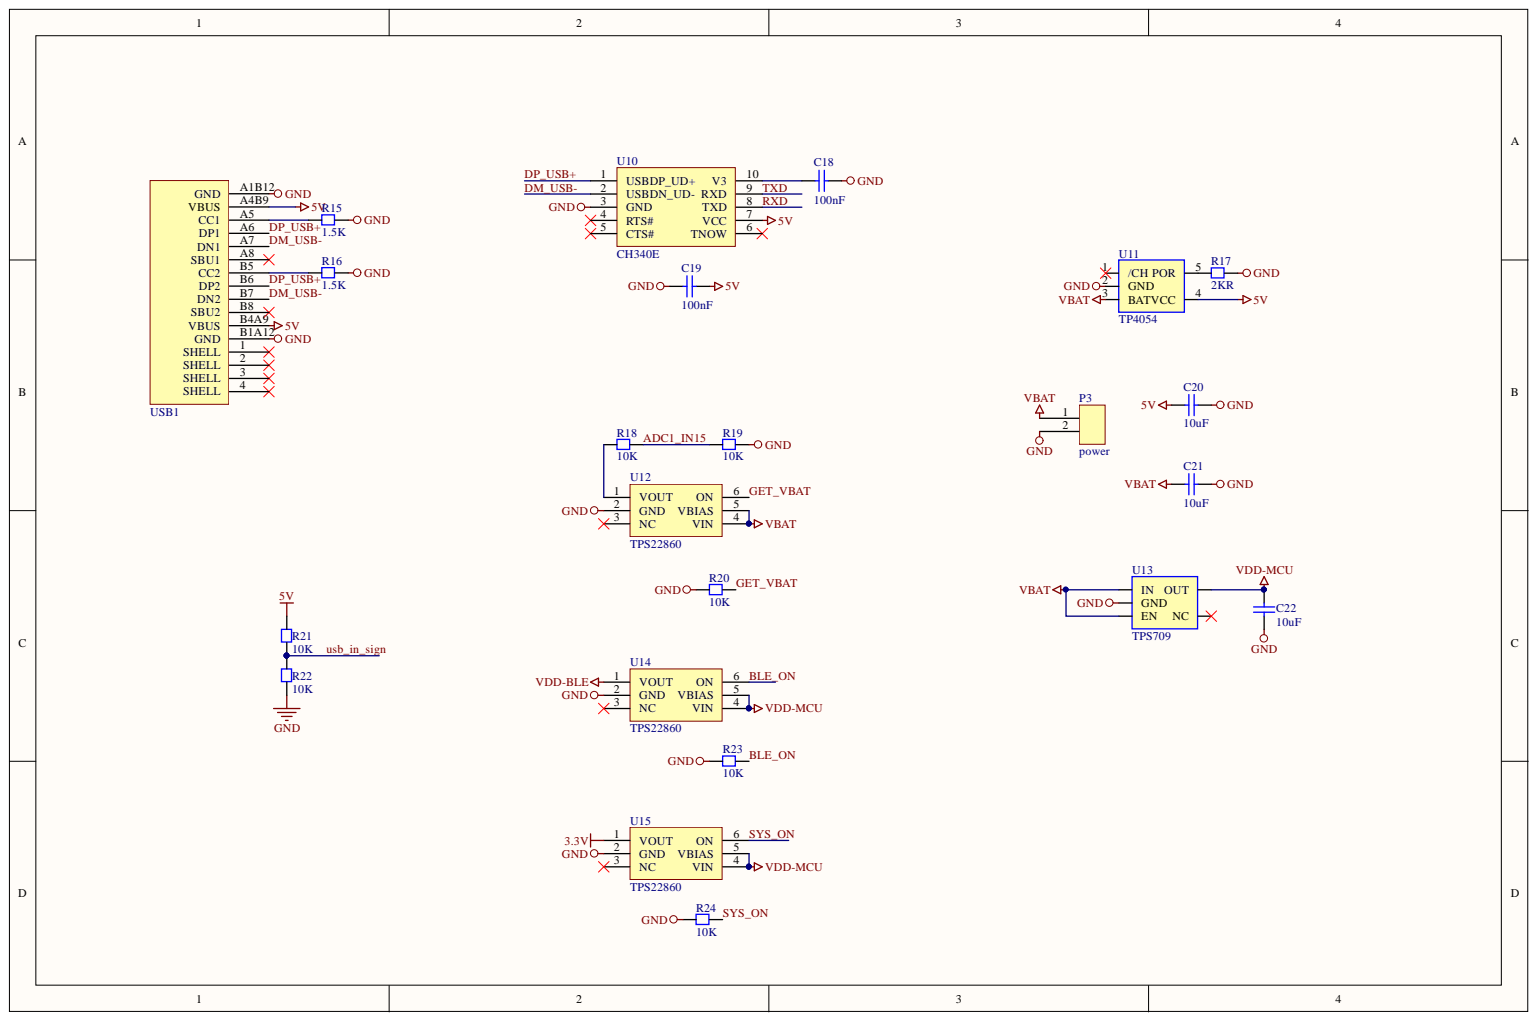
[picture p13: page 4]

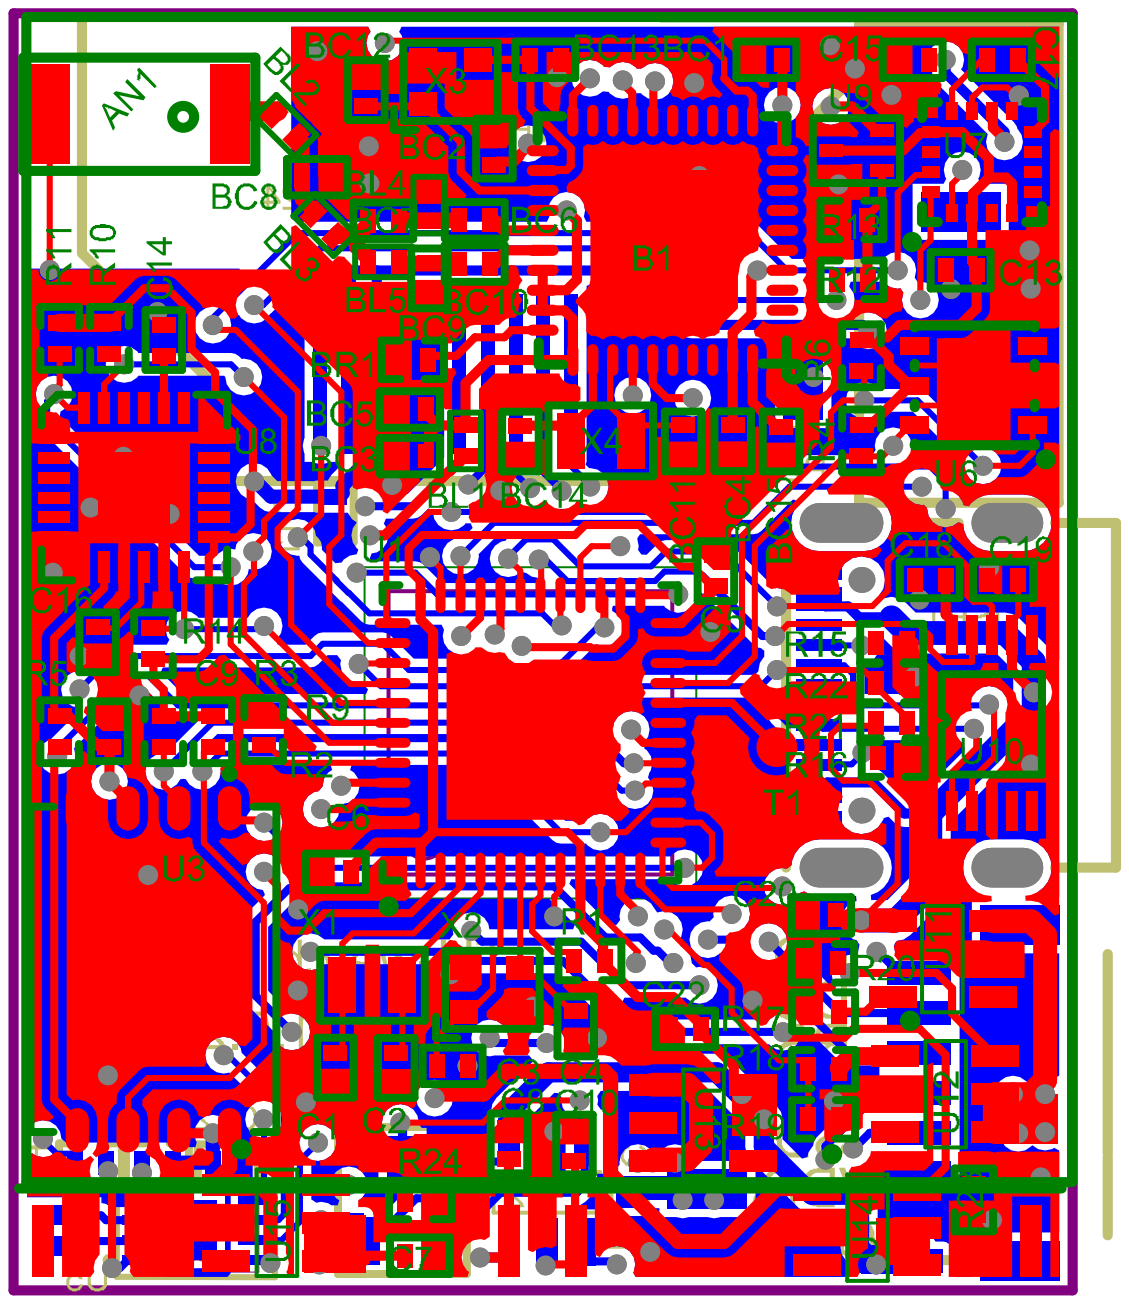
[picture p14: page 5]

Comment | Description | Designator | Footprint | LibRef | Quantity
AN9520-245 | 2.4G全向天线 蓝牙天 线 陶瓷贴片 WIFI内 置 | AN1 | AN-5120 | AN9520-245 | 1
CC2541 | 低功耗蓝牙芯片 | B1 | QFN40-CC254X | CC2541 | 1
100nF | 贴片电容 | BC1, BC2, BC4, C5, C6, C7, C9, C11, C12, C13, C16, C18, C19 | CC1005-0402 | Chip capacitor | 13
220nF | 贴片电容 | BC3 | CC1005-0402 | Chip capacitor | 1
10uF | 贴片电容 | BC5, C20, C21, C22 | CC1005-0402 | Chip capacitor | 4
18pF | 贴片电容 | BC6, BC10 | CC1005-0402 | Chip capacitor | 2
1pF | 贴片电容 | BC7, BC8, BC9, C8, C10 | CC1005-0402 | Chip capacitor | 5
15pF | 贴片电容 | BC11, BC14, C1, C2 | CC1005-0402 | Chip capacitor | 4
27pF | 贴片电容 | BC12, BC13, C3, C4 | CC1005-0402 | Chip capacitor | 4
100pF | 贴片电容 | BC15 | CC1005-0402 | Chip capacitor | 1
2nH | 0402封装的电感 | BL1, BL4, BL5 | Inductor-0402 | Inductor-0402 | 3
1nH | 0402封装的电感 | BL2, BL3 | Inductor-0402 | Inductor-0402 | 2
56KR | 贴片电阻 | BR1 | CR1005-0402 | Chip resistor | 1
2.2uF | 贴片电容 | C14 | CC1005-0402 | Chip capacitor | 1
4.7uF | 贴片电容 | C15 | CC1005-0402 | Chip capacitor | 1
0.22uF | 贴片电容 | C17 | CC1005-0402 | Chip capacitor | 1
TFT LED | 1.3寸显示屏幕 | L1 | LCD-1.3-(2) | LCD-IPSscreen-1.3 | 1
power | | P0 | POWER2 | power | 1
power | | P2, P3 | POWER-3.7V | power | 2
10K | 贴片电阻 | R1, R2, R4, R6, R10, R11, R13, R14, R18, R19, R20, R21, R22, R23, R24 | CR1005-0402 | Chip resistor | 15
47K | 贴片电阻 | R3, R5, R9 | CR1005-0402 | Chip resistor | 3
4.7K | 贴片电阻 | R7 | CR1005-0402 | Chip resistor | 1
1K | 贴片电阻 | R8, R12 | CR1005-0402 | Chip resistor | 2
1.5K | 贴片电阻 | R15, R16 | CR1005-0402 | Chip resistor | 2
2KR | 贴片电阻 | R17 | CR1005-0402 | Chip resistor | 1
SH1.0-7P | 间距为1mm的端子 | SH1 | SH1.0-7P | SH1.0-7P | 1
测试点 | 测试点 | T1 | 测试点 | 测试点 | 1
STM32L431CCU6 | stm32低功耗单片机 主频80MHz | U1 | STM32-UFQFPN48_N | STM32L431CCU6 | 1
BS812A-1 | 触摸按键 两路 SOP23-6封装极简电 路 | U2 | SOT23-6 | BS812A-1 | 1
W25Q64JVEIQ | FLASH | U3 | WSON-8_L8.0-W6.10-P1.27-TL-EP | W25Q256JVEIQ | 1
SI2305 | PMOS场效应MOS管 SOT-23 | U4 | SOT-23 | SI2305 | 1
ST25DV04k | NFC芯片4K存储空间 | U5 | UFDFPN8 | ST25DV04k | 1
SI7020 | 温湿度传感器芯片 | U6 | DFN-6 | SI7020 | 1
HMC5883L | 三轴罗盘 | U7 | LPCC-16_L3.0-W3.0-P0.50-BL | HMC5883L | 1
MPU6050 | 陀螺仪 | U8 | QFN24 - duplicate | MPU6050 | 1
MMBT3904TT1G | NPN 电流 - 集电极 （Ic）（最大值）： 200mA 电压 - 集射极 击穿（最大值）：40V SOT-23-3 | U9 | SOT-416 | MMBT3904TT1G | 1
CH340E | usd转串口芯片 MSOP10封装 | U10 | MSOP-10 | CH340E | 1
TP4054 | 迷你充电IC SOT-23-5 | U11 | SOT23-5 | TP4054 | 1
TPS22860 | 超低泄漏电流负载开 关 超低泄漏电流负载 开关 它可支持最大 200mA 的持续电 流。 此开关可由一个 打开/关闭输入 (ON) 控制 | U12, U14, U15 | SOT23-6 | TPS22860 | 3
TPS709 | 3.3V降压IC SOT23-5 封装 最大输出150ma 电流 | U13 | SOT23-5 | TPS709 | 1
Tpye-c 16P | 16P 封装的TYPE -c接 口 4固定插脚 双向 | USB1 | TYPE-C 16P | Tpye-c 16P | 1
32.768Khz | 2012封装的时钟晶振 | X1, X4 | XTAL-2012 | XTAL 2012 | 2
32Mhz | 2016封装的晶振 | X2, X3 | XTAL-2016 | XTAL 2016 | 2

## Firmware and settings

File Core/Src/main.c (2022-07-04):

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
/* Includes ------------------------------------------------------------------*/
#include "main.h"
#include "cmsis_os.h"
#include "adc.h"
#include "dma.h"
#include "i2c.h"
#include "rtc.h"
#include "spi.h"
#include "tim.h"
#include "usart.h"
#include "gpio.h"

/* USER CODE BEGIN Includes */

#include "stdio.h"


#include "lcd_init.h"
#include "lcd.h"
#include "getword.h"
//#include "pic.h"
//#include "picmain.h"


#include "mpu6050.h"
#include "inv_mpu.h"
#include "inv_mpu_dmp_motion_driver.h"

#include "hmc5883l.h"

#include "SI7021.h"

#include "w25q64.h"

#include "taskfun.h"


#include "string.h"
#include "ymodel.h"
//lvgl相关的库
#include "lvgl.h"
#include "lv_port_disp.h"
#include "lv_port_indev.h"
#include "lv_apps\demo\demo.h"

#include "testtaskFun.h" //测试类的函数库 //里面的函数全部都用来做测试
#include "guitest.h"  //lvgl的相关测试
#include "app_menu.h" //菜单目录
/* USER CODE END Includes */

/* USER CODE BEGIN PTD */
#ifdef __GNUC__
#define PUTCHAR_PROTOTYPE int __io_putchar(int ch)
#else
#define PUTCHAR_PROTOTYPE int fputc(int ch, FILE *f)
#endif
PUTCHAR_PROTOTYPE
{
    //具体哪个串口可以更改huart1为其它串口
    HAL_UART_Transmit(&huart1, (uint8_t *)&ch, 1, 0xffff);
    return ch;
}

void SystemClock_Config(void);
void MX_FREERTOS_Init(void);

int main(void)
{
    /* USER CODE BEGIN 1 */
//#define	test_model
#ifdef test_model
    int i;

    float pitch,roll,yaw; 		//欧拉角
    short aacx,aacy,aacz;		//加速度传感器原始数据
    short gyrox,gyroy,gyroz;	//陀螺仪原始数据
    short temp;					//温度

    float Curent_Angle;

    unsigned char USB_in_SIGN = 0;
    unsigned char KEY_1 = 0;
    unsigned char KEY_2 = 0;

    float ADC_Value_BATTERY = 0;

    int Hp = 0;
    unsigned char GBH = 0x00;
    unsigned char GBL = 0x00;
    unsigned char size = 128;
    int t=0;
#endif


    HAL_Init();


    SystemClock_Config();

    MX_GPIO_Init();
    MX_DMA_Init();
    MX_SPI1_Init();
    MX_USART1_UART_Init();
    MX_TIM1_Init();
    MX_I2C1_Init();
    MX_I2C2_Init();
    MX_USART2_UART_Init();
    MX_TIM2_Init();
    MX_RTC_Init();
    MX_ADC1_Init();
    //把 lv_tick_inc(1)放在了 vApplicationTickHook里面 所以tim7不用了
		// MX_TIM7_Init();
    /* USER CODE BEGIN 2 */
    init_task();
    lv_init();						//lvgl系统初始化
    lv_port_disp_init();	//lvgl显示接口初始化,放在lv_init()的后面
    lv_port_indev_init();	//lvgl输入接口初始化,放在lv_init()的后面
    osKernelInitialize();  /* Call init function for freertos objects (in freertos.c) */
    MX_FREERTOS_Init();
    osKernelStart();
    while(1)
    {

    }

}

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


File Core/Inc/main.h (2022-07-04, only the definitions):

#define LCD0_Pin GPIO_PIN_13
#define LCD0_GPIO_Port GPIOC
#define LCD_CS_Pin GPIO_PIN_1
#define LCD_CS_GPIO_Port GPIOA
#define FLASH_CS_Pin GPIO_PIN_4
#define FLASH_CS_GPIO_Port GPIOA
#define BLE_ON_Pin GPIO_PIN_12
#define BLE_ON_GPIO_Port GPIOB
#define SYS_ON_Pin GPIO_PIN_13
#define SYS_ON_GPIO_Port GPIOB
#define V_EH_Pin GPIO_PIN_14
#define V_EH_GPIO_Port GPIOB
#define ST25DV_GIO_Pin GPIO_PIN_15
#define ST25DV_GIO_GPIO_Port GPIOB
#define GET_VBAT_Pin GPIO_PIN_12
#define GET_VBAT_GPIO_Port GPIOA
#define usb_in_sign_Pin GPIO_PIN_3
#define usb_in_sign_GPIO_Port GPIOB
#define MPU_INT_Pin GPIO_PIN_5
#define MPU_INT_GPIO_Port GPIOB
#define LCD_DC_Pin GPIO_PIN_8
#define LCD_DC_GPIO_Port GPIOB
#define LCD_RES_Pin GPIO_PIN_9
#define LCD_RES_GPIO_Port GPIOB

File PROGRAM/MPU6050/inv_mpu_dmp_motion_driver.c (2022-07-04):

/*
 $License:
    Copyright (C) 2011-2012 InvenSense Corporation, All Rights Reserved.
    See included License.txt for License information.
 $
 */
/**
 *  @addtogroup  DRIVERS Sensor Driver Layer
 *  @brief       Hardware drivers to communicate with sensors via I2C.
 *
 *  @{
 *      @file       inv_mpu_dmp_motion_driver.c
 *      @brief      DMP image and interface functions.
 *      @details    All functions are preceded by the dmp_ prefix to
 *                  differentiate among MPL and general driver function calls.
 */
#include <stdio.h>
#include <stdint.h>
#include <stdlib.h>
#include <string.h>
#include <math.h>
#include "inv_mpu.h"
#include "inv_mpu_dmp_motion_driver.h"
#include "dmpKey.h"
#include "dmpmap.h"
#include "usart.h"


//定义目标板采用MSP430
#define  MOTION_DRIVER_TARGET_MSP430

/* The following functions must be defined for this platform:
 * i2c_write(unsigned char slave_addr, unsigned char reg_addr,
 *      unsigned char length, unsigned char const *data)
 * i2c_read(unsigned char slave_addr, unsigned char reg_addr,
 *      unsigned char length, unsigned char *data)
 * delay_ms(unsigned long num_ms)
 * get_ms(unsigned long *count)
 */
#if defined MOTION_DRIVER_TARGET_MSP430
//#include "msp430.h"
//#include "msp430_clock.h"
#define delay_ms    HAL_Delay
#define get_ms      mget_ms
#define log_i 		printf
#define log_e  		printf

#elif defined EMPL_TARGET_MSP430
#include "msp430.h"
#include "msp430_clock.h"
#include "log.h"
#define delay_ms    msp430_delay_ms
#define get_ms      msp430_get_clock_ms
#define log_i       MPL_LOGI
#define log_e       MPL_LOGE

#elif defined EMPL_TARGET_UC3L0
/* Instead of using the standard TWI driver from the ASF library, we're using
 * a TWI driver that follows the slave address + register address convention.
 */
#include "delay.h"
#include "sysclk.h"
#include "log.h"
#include "uc3l0_clock.h"
/* delay_ms is a function already defined in ASF. */
#define get_ms  uc3l0_get_clock_ms
#define log_i       MPL_LOGI
#define log_e       MPL_LOGE

#else
#error  Gyro driver is missing the system layer implementations.
#endif

/* These defines are copied from dmpDefaultMPU6050.c in the general MPL
 * releases. These defines may change for each DMP image, so be sure to modify
 * these values when switching to a new image.
 */
#define CFG_LP_QUAT             (2712)
#define END_ORIENT_TEMP         (1866)
#define CFG_27                  (2742)
#define CFG_20                  (2224)
#define CFG_23                  (2745)
#define CFG_FIFO_ON_EVENT       (2690)
#define END_PREDICTION_UPDATE   (1761)
#define CGNOTICE_INTR           (2620)
#define X_GRT_Y_TMP             (1358)
#define CFG_DR_INT              (1029)
#define CFG_AUTH                (1035)
#define UPDATE_PROP_ROT         (1835)
#define END_COMPARE_Y_X_TMP2    (1455)
#define SKIP_X_GRT_Y_TMP        (1359)
#define SKIP_END_COMPARE        (1435)
#define FCFG_3                  (1088)
#define FCFG_2                  (1066)
#define FCFG_1                  (1062)
#define END_COMPARE_Y_X_TMP3    (1434)
#define FCFG_7                  (1073)
#define FCFG_6                  (1106)
#define FLAT_STATE_END          (1713)
#define SWING_END_4             (1616)
#define SWING_END_2             (1565)
#define SWING_END_3             (1587)
#define SWING_END_1             (1550)
#define CFG_8                   (2718)
#define CFG_15                  (2727)
#define CFG_16                  (2746)
#define CFG_EXT_GYRO_BIAS       (1189)
#define END_COMPARE_Y_X_TMP     (1407)
#define DO_NOT_UPDATE_PROP_ROT  (1839)
#define CFG_7                   (1205)
#define FLAT_STATE_END_TEMP     (1683)
#define END_COMPARE_Y_X         (1484)
#define SKIP_SWING_END_1        (1551)
#define SKIP_SWING_END_3        (1588)
#define SKIP_SWING_END_2        (1566)
#define TILTG75_START           (1672)
#define CFG_6                   (2753)
#define TILTL75_END             (1669)
#define END_ORIENT              (1884)
#define CFG_FLICK_IN            (2573)
#define TILTL75_START           (1643)
#define CFG_MOTION_BIAS         (1208)
#define X_GRT_Y                 (1408)
#define TEMPLABEL               (2324)
#define CFG_ANDROID_ORIENT_INT  (1853)
#define CFG_GYRO_RAW_DATA       (2722)
#define X_GRT_Y_TMP2            (1379)

#define D_0_22                  (22+512)
#define D_0_24                  (24+512)

#define D_0_36                  (36)
#define D_0_52                  (52)
#define D_0_96                  (96)
#define D_0_104                 (104)
#define D_0_108                 (108)
#define D_0_163                 (163)
#define D_0_188                 (188)
#define D_0_192                 (192)
#define D_0_224                 (224)
#define D_0_228                 (228)
#define D_0_232                 (232)
#define D_0_236                 (236)

#define D_1_2                   (256 + 2)
#define D_1_4                   (256 + 4)
#define D_1_8                   (256 + 8)
#define D_1_10                  (256 + 10)
#define D_1_24                  (256 + 24)
#define D_1_28                  (256 + 28)
#define D_1_36                  (256 + 36)
#define D_1_40                  (256 + 40)
#define D_1_44                  (256 + 44)
#define D_1_72                  (256 + 72)
#define D_1_74                  (256 + 74)
#define D_1_79                  (256 + 79)
#define D_1_88                  (256 + 88)
#define D_1_90                  (256 + 90)
#define D_1_92                  (256 + 92)
#define D_1_96                  (256 + 96)
#define D_1_98                  (256 + 98)
#define D_1_106                 (256 + 106)
#define D_1_108                 (256 + 108)
#define D_1_112                 (256 + 112)
#define D_1_128                 (256 + 144)
#define D_1_152                 (256 + 12)
#define D_1_160                 (256 + 160)
#define D_1_176                 (256 + 176)
#define D_1_178                 (256 + 178)
#define D_1_218                 (256 + 218)
#define D_1_232                 (256 + 232)
#define D_1_236                 (256 + 236)
#define D_1_240                 (256 + 240)
#define D_1_244                 (256 + 244)
#define D_1_250                 (256 + 250)
#define D_1_252                 (256 + 252)
#define D_2_12                  (512 + 12)
#define D_2_96                  (512 + 96)
#define D_2_108                 (512 + 108)
#define D_2_208                 (512 + 208)
#define D_2_224                 (512 + 224)
#define D_2_236                 (512 + 236)
#define D_2_244                 (512 + 244)
#define D_2_248                 (512 + 248)
#define D_2_252                 (512 + 252)
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

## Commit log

2022-07-04 2022.7.4 初始化仓库，上传工程
2022-07-04 上传pcb相关设计以及原理图
    [01-MCU-V2.1.SchDoc, 01-MCU-V2.2.SchDoc, 01-MCU-V2.3.SchDoc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]

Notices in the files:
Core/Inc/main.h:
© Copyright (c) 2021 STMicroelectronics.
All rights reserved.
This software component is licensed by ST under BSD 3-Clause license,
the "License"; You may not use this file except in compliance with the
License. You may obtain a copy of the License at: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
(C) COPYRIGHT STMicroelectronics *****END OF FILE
